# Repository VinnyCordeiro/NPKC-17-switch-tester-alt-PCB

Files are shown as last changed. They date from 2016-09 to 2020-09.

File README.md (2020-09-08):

# NPKC 17 Switch Tester alternative PCB
Alternative PCB to convert the NPKC 17 switch tester (https://www.massdrop.com/buy/npkc-switch-tester?mode=guest_open or https://www.massdrop.com/buy/npkc-17-switch-tester?mode=guest_open) into a number pad. It is small enough to be modified by the free version of [EAGLE](https://cadsoft.io/). You can buy the PCB through [Dirty PCBs](https://dirtypcbs.com/store/designer/details/9479/676/aunk-numpad).

The Atmel ATmega32U2 microcontroller can be programmed with both [TMK keyboard firmware](https://github.com/tmk/tmk_keyboard) and [QMK keyboard firmware](https://github.com/qmk/qmk_firmware). TMK code for this PCB can be found [here](https://github.com/VinnyCordeiro/tmk_keyboard/tree/master/keyboard/AUNK_Numpad), while the QMK code (and a standard number pad firmware) is now available here.

As of September 08, 2020, the design is still untested.

Updates
-------
#### 13/September/2016
Initial release. Included are all custom libraries for EAGLE.

#### 15/January/2019
Uploaded a tentative firmware made with the help of [Keyboard Firmware Builder](https://kbfirmware.com/). Design still untested.

#### 08/September/2020
Remebered to add the link for people to buy the PCB. Design still untested (I'm off from the mechanical keyboards hobby for personal reasons).

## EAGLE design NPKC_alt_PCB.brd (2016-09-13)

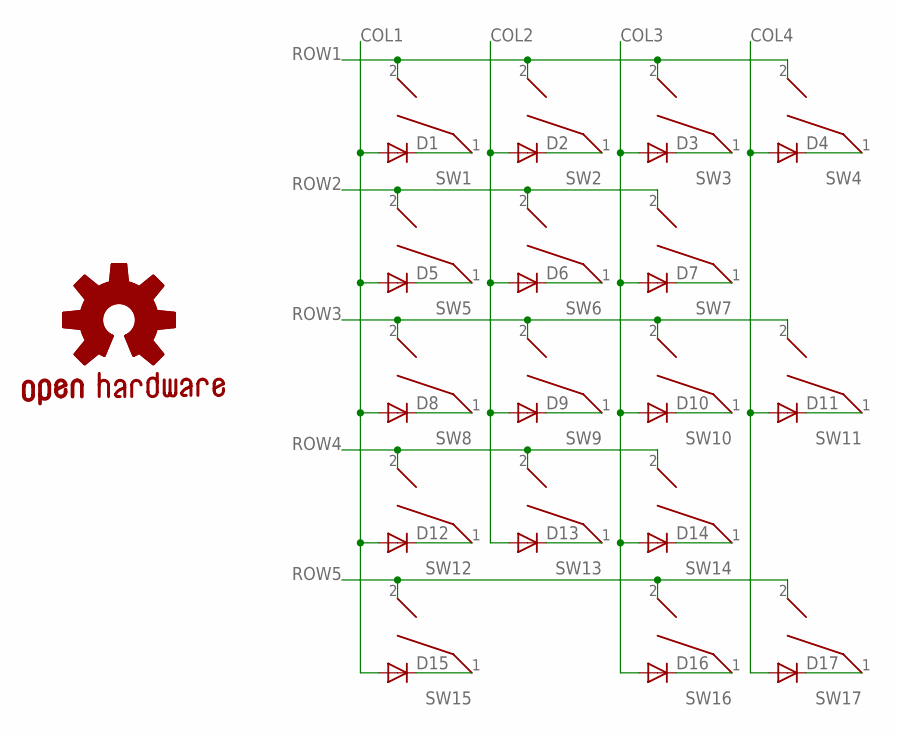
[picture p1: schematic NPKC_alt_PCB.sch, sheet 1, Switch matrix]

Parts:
D1, D2, D3, D4, D5, D6, D7, D8, D9, D10, D11, D12, D13, D14, D15, D16, D17: CGRM4001-G; SOD-123_MINI-SMA
GOLD_ORB_SM1: OSHWLOGO_GOLD_ORB_SM; OSHW2
SW1: Num_Lock; MX1A-XXNW
SW2: NP_/; MX1A-XXNW
SW3: NP_*; MX1A-XXNW
SW4: NP_-; MX1A-XXNW
SW5: NP_7; MX1A-XXNW
SW6: NP_8; MX1A-XXNW
SW7: NP_9; MX1A-XXNW
SW8: NP_4; MX1A-XXNW
SW9: NP_5; MX1A-XXNW
SW10: NP_6; MX1A-XXNW
SW11: NP_+; MX1A-XXNW
SW12: NP_1; MX1A-XXNW
SW13: NP_2; MX1A-XXNW
SW14: NP_3; MX1A-XXNW
SW15: NP_0; MX1A-XXNW
SW16: NP_.; MX1A-XXNW
SW17: NP_Enter; MX1A-XXNW

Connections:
COL1: D1.A, D5.A, D8.A, D12.A, D15.A; also elsewhere on the board
COL2: D2.A, D6.A, D9.A, D13.A; also elsewhere on the board
COL3: D3.A, D7.A, D10.A, D14.A, D16.A; also elsewhere on the board
COL4: D4.A, D11.A, D17.A; also elsewhere on the board
unnamed: D1.C, SW1.1
unnamed: D2.C, SW2.1
unnamed: D3.C, SW3.1
unnamed: D4.C, SW4.1
unnamed: D5.C, SW5.1
unnamed: D6.C, SW6.1
unnamed: D7.C, SW7.1
unnamed: D8.C, SW8.1
unnamed: D9.C, SW9.1
unnamed: D10.C, SW10.1
unnamed: D11.C, SW11.1
unnamed: D12.C, SW12.1
unnamed: D13.C, SW13.1
unnamed: D14.C, SW14.1
unnamed: D15.C, SW15.1
unnamed: D16.C, SW16.1
unnamed: D17.C, SW17.1
ROW1: SW1.2, SW2.2, SW3.2, SW4.2; also elsewhere on the board
ROW2: SW5.2, SW6.2, SW7.2; also elsewhere on the board
ROW3: SW8.2, SW9.2, SW10.2, SW11.2; also elsewhere on the board
ROW4: SW12.2, SW13.2, SW14.2; also elsewhere on the board
ROW5: SW15.2, SW16.2, SW17.2; also elsewhere on the board

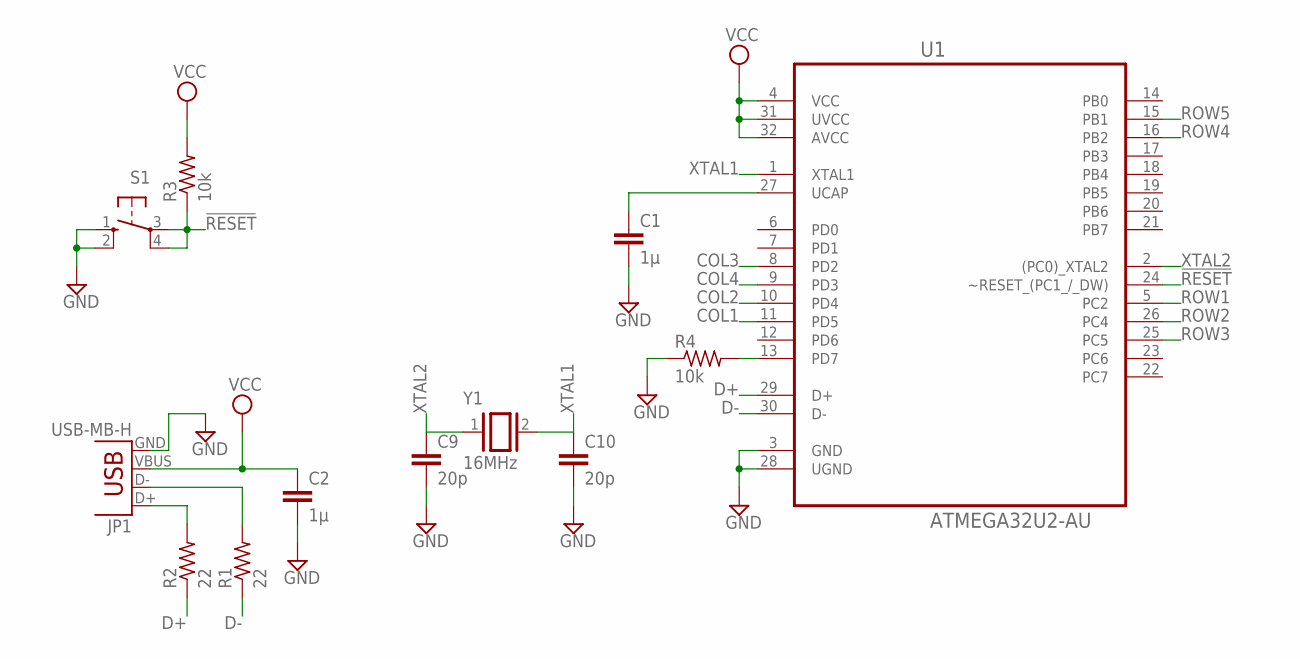
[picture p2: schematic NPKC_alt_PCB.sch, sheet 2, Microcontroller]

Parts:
C1: 1µ; C0805K
C2: 1µ; C0805
C9, C10: 20p; C0805K
JP1: USB-MB-H
R1, R2: 22; R0805
R3, R4: 10k; R0805
S1: 10-XX; B3F-10XX
U1: ATMEGA32U2-AU; QFP80P900X900X120-32N
Y1: 16MHz; QS

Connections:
!RESET!: R3.1, S1.3, S1.4 (P1), U1.24 (~RESET_(PC1_/_DW))
COL1: U1.11 (PD5); also elsewhere on the board
COL2: U1.10 (PD4); also elsewhere on the board
COL3: U1.8 (PD2); also elsewhere on the board
COL4: U1.9 (PD3); also elsewhere on the board
D+: R2.1, U1.29 (D+)
D-: R1.1, U1.30 (D-)
GND: C1.2, C2.2, C9.2, C10.2, JP1.GND, R4.1, S1.1 (S), S1.2 (S1), U1.3 (GND), U1.28 (UGND)
unnamed: C1.1, U1.27 (UCAP)
unnamed: R4.2, U1.13 (PD7)
unnamed: JP1.D+, R2.2
unnamed: JP1.D-, R1.2
ROW1: U1.5 (PC2); also elsewhere on the board
ROW2: U1.26 (PC4); also elsewhere on the board
ROW3: U1.25 (PC5); also elsewhere on the board
ROW4: U1.16 (PB2); also elsewhere on the board
ROW5: U1.15 (PB1); also elsewhere on the board
VCC: C2.1, JP1.VBUS, R3.2, U1.4 (VCC), U1.31 (UVCC), U1.32 (AVCC)
XTAL1: C10.1, U1.1 (XTAL1), Y1.2
XTAL2: C9.1, U1.2 ((PC0)_XTAL2), Y1.1

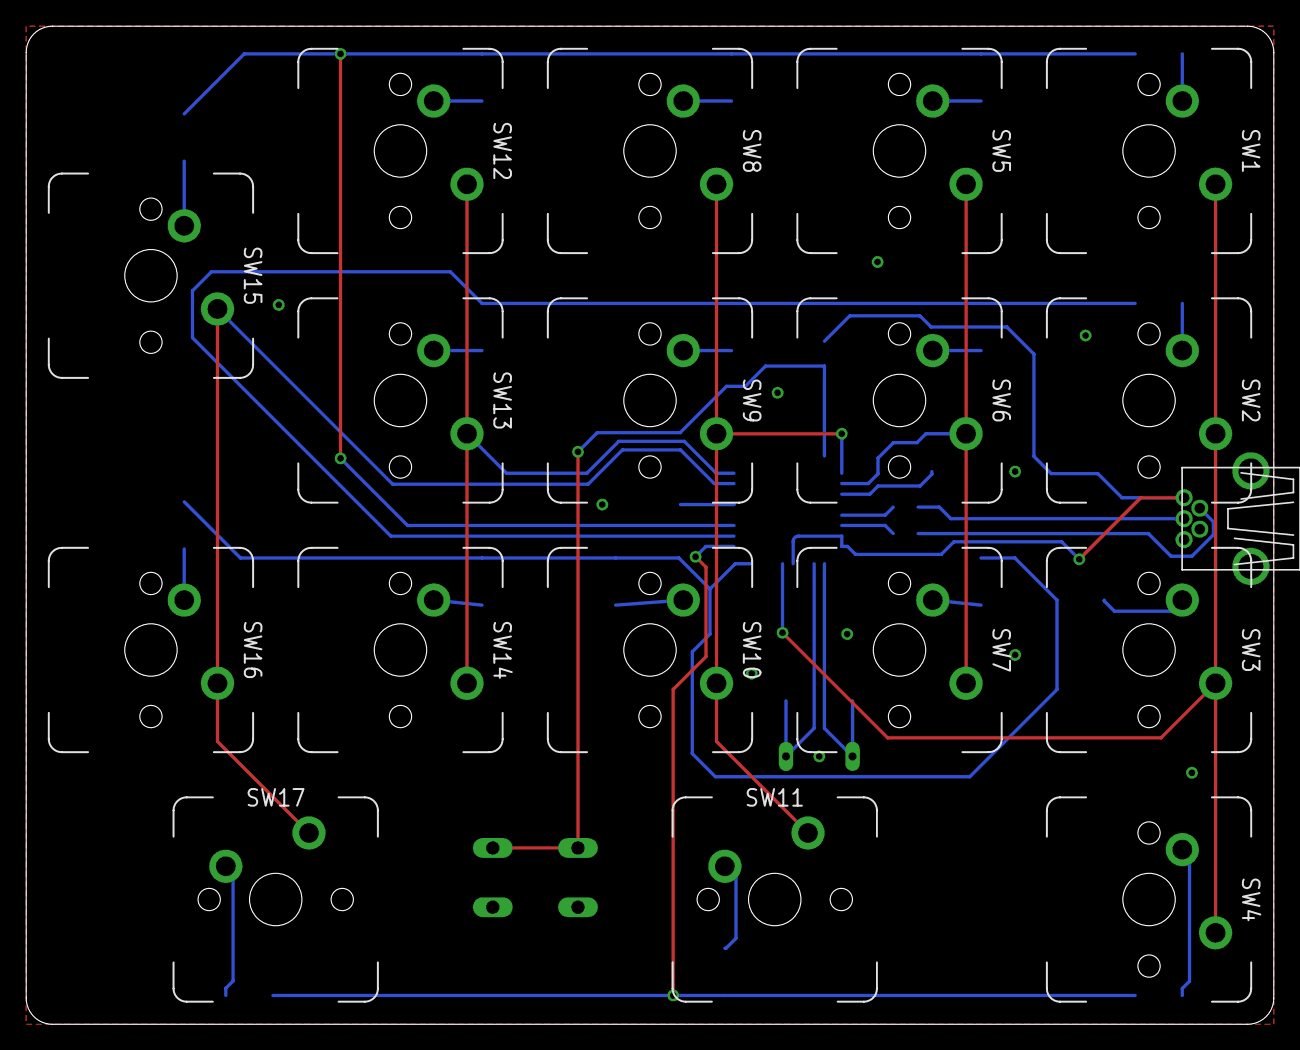
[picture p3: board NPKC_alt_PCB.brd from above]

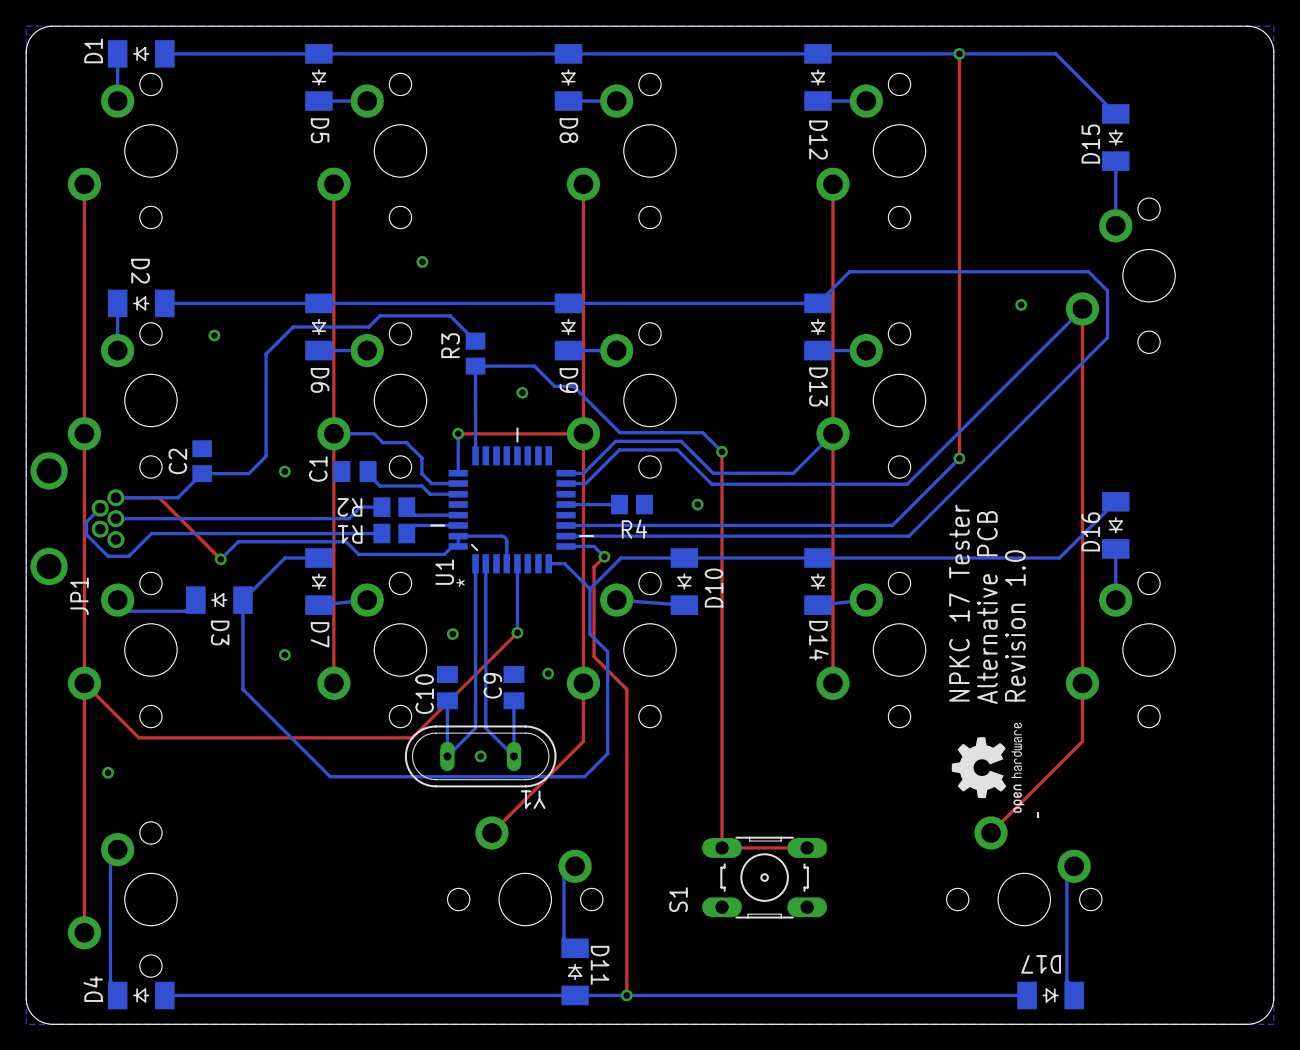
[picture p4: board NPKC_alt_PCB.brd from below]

Board: 2 copper layers, 95.2 x 76.2 mm, 47 parts (30 on the bottom side), 37 nets.

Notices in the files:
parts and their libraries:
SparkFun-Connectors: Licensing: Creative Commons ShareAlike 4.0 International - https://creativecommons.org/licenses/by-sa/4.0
